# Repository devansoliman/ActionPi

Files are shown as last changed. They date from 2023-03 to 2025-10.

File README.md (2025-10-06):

# ActionPi
The open-source action camera.

## Build
1. Install `DietPi` using the [docs](https://dietpi.com/docs/install/). Add the line `dtoverlay=imx219` to `config.txt` in the `bootfs` partition.
2. Put the contents of `software` into an easily accessible directory.
3. Move `autostart.service` into `/etc/systemd/system/`. You may have to edit the path to `action.py`.
4. Run `sudo systemctl enable autostart.service`.
5. Install the following dependencies:
  - [rpi-lgpio](https://pypi.org/project/rpi-lgpio/)
  - [picamera2](https://pypi.org/project/picamera2/)
  - [luma.oled](https://luma-oled.readthedocs.io/en/latest/software.html)
  - ffmpeg
6. Open `__init__.py` in `/usr/lib/python3/dist-packages/luma/oled/device/`. Find `__init__` function under `class ssd1306(device)`. Change `height` parameter from **64** to **32**.

## Assembly Guide
🚧 In development.

### 3D Printing
I recommend using a filament with impact, UV, and fatigue resistance. Most recent prototype printed in PETG with up to 4 wall lines (0.4 mm line width).

### Parts
- Raspberry Pi Zero
- Arducam IMX219 camera (B0390)
- SSD1306 128x32 OLED
- TP4056 Li-ion charging module (USB-C input)
- 18650 Li-ion cell
- tactile button (12mm x 12mm)
- SS12D10 slide switch
- 26 AWG wire
- 2x nickel strips
- 4x m2.5 x 8mm flat head screws
- 2x m2.5 x 5mm flat head screws
- 4x m2 x 4mm flat head screws

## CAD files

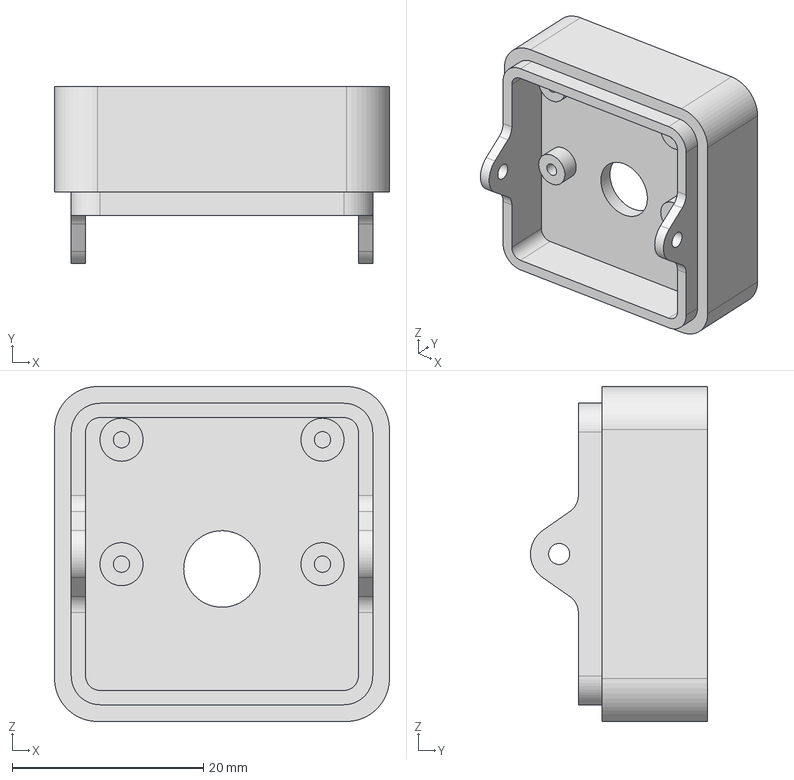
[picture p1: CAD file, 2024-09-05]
hardware/STEP/lens adapter.stp
35.0 x 18.5 x 35.0 mm

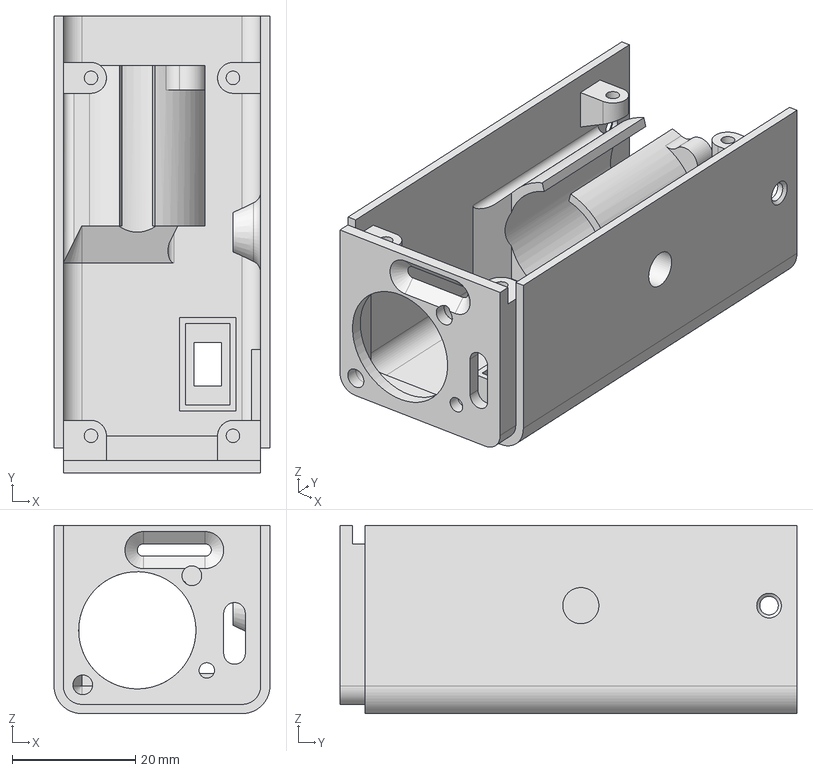
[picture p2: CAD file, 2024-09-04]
hardware/STEP/case.stp
35.0 x 74.0 x 30.5 mm

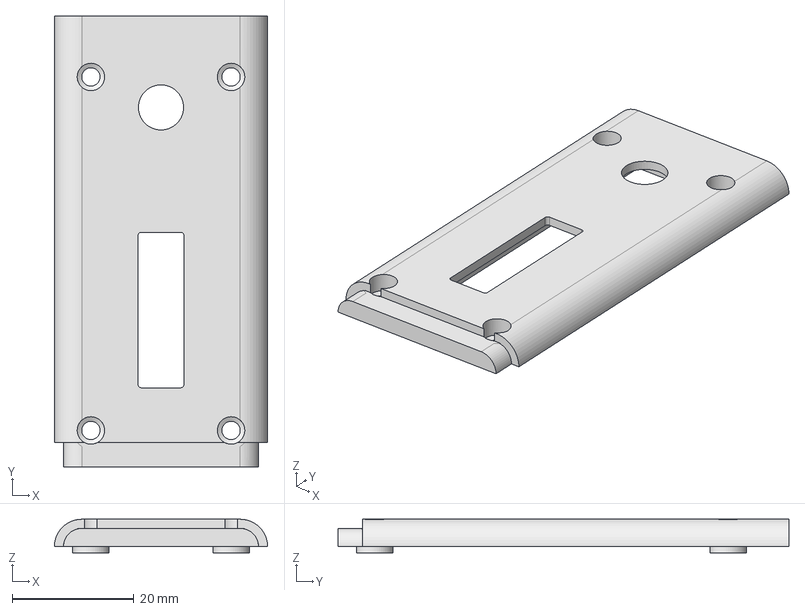
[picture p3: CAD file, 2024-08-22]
hardware/STEP/faceplate.stp
35.0 x 74.0 x 5.50 mm

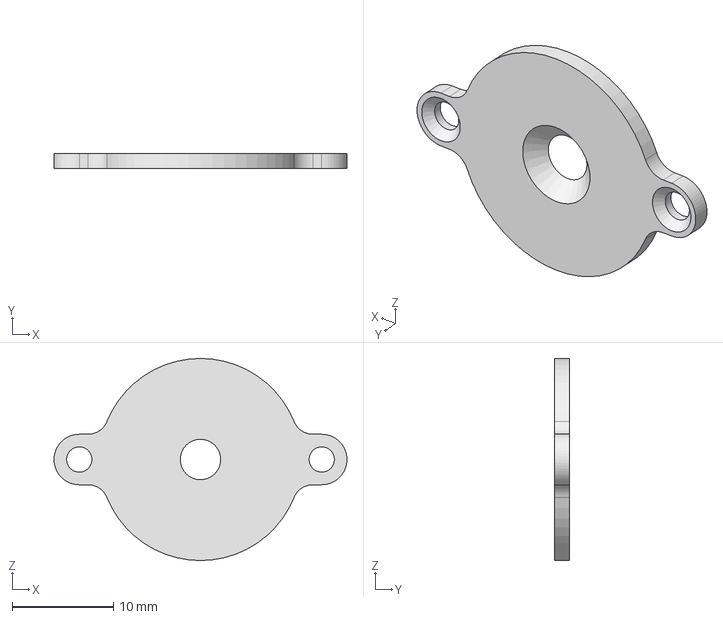
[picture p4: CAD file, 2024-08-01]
hardware/STEP/negative terminal.stp
29.0 x 1.50 x 20.0 mm

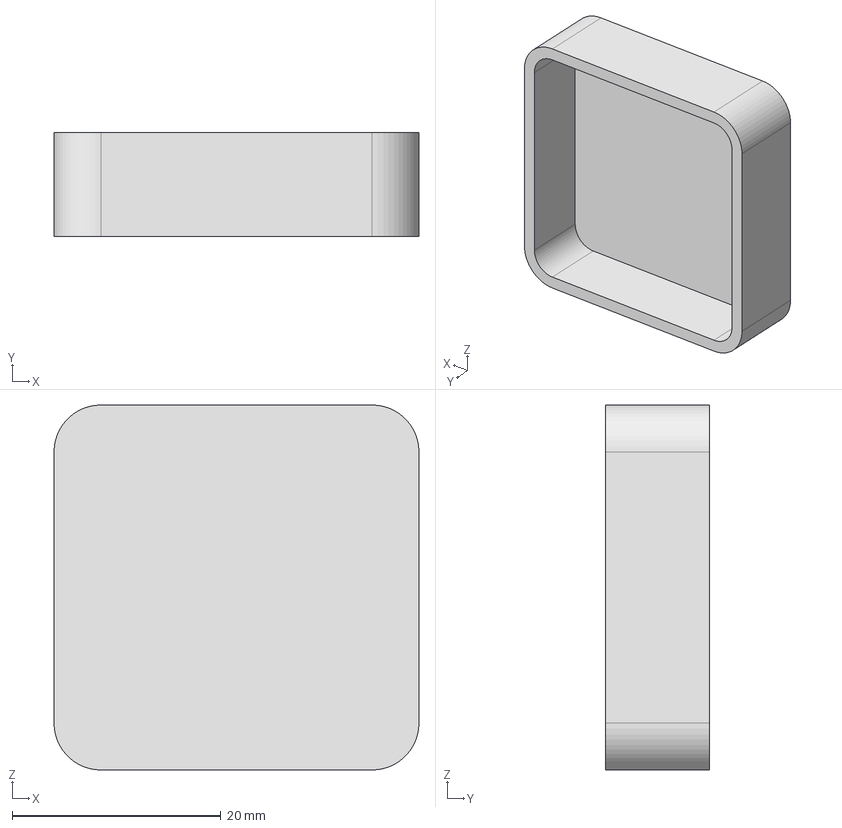
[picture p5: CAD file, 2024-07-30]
hardware/STEP/dust cap.stp
35.0 x 10.0 x 35.0 mm

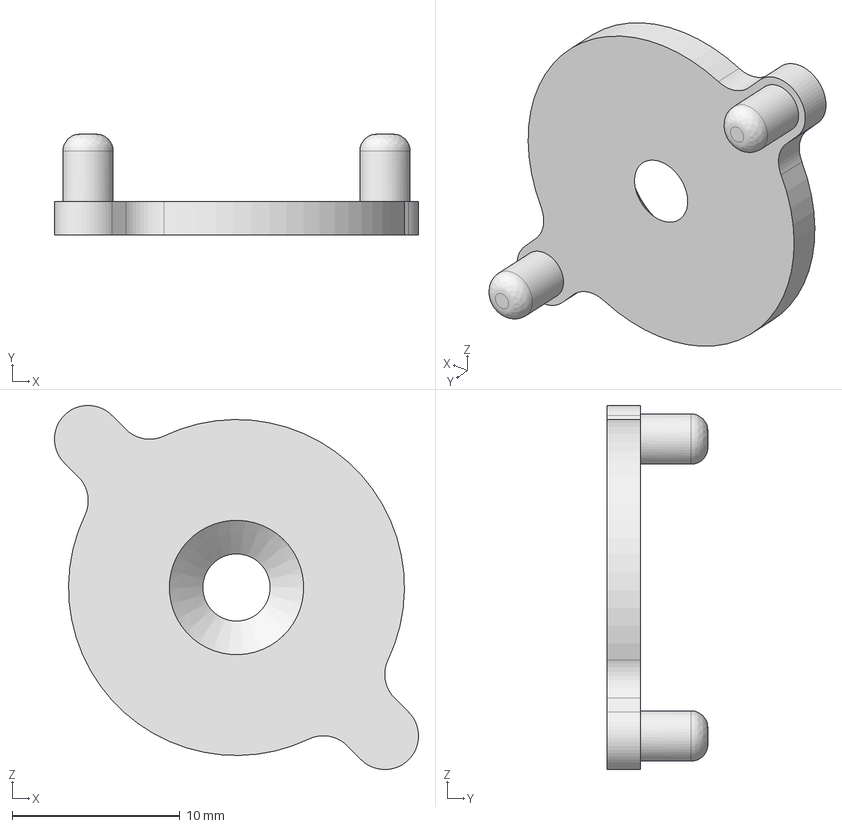
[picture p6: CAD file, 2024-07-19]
hardware/STEP/positive terminal.stp
21.7 x 6.00 x 21.7 mm

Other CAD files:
hardware/STL/case.stl
hardware/STL/dust cap.stl
hardware/STL/faceplate.stl
hardware/STL/lens adapter.stl
hardware/STL/negative terminal.stl
hardware/STL/positive terminal.stl

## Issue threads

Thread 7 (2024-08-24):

battery monitoring

devansoliman, 2024-08-24:
The Raspberry Pi Zero doesn't have an ADC, so we'll need another module to track the battery voltage.

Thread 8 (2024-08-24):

text compression

devansoliman, 2024-08-24:
`luma.oled.device.ssd1306` library uses the 128x64 version instead of 128x32

devansoliman, 2024-08-28:
Fix: change `height=64` parameter to `height=32` in `class ssd1306(device).__init__` in `/usr/lib/python3/dist-packages/luma/oled/device/__init__.py`.

Closed 2024-08-28.

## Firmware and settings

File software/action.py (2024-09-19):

import RPi.GPIO as GPIO
from picamera2 import Picamera2
from picamera2.encoders import H264Encoder
from picamera2.outputs import FfmpegOutput
from libcamera import Transform
from datetime import datetime
import threading
import os
from signal import pause

from luma.core.interface.serial import i2c
from luma.core.render import canvas
from luma.oled.device import ssd1306

from PIL import Image, ImageFont


# max CPU priority
os.nice(-20)

# video recording state
recording = False

# time counter
timer = 0

# button pin
button = 5

# configure GPIO
GPIO.setwarnings(False)
GPIO.setmode(GPIO.BCM)
GPIO.setup(button, GPIO.IN, pull_up_down=GPIO.PUD_UP)

# initialize display
serial = i2c(port=1, address=0x3C)
device = ssd1306(serial)

# splash image
splash = Image.open("splash.jpg")
device.display(splash.convert(device.mode))

# configure picamera2
picam2 = Picamera2()
video_config = picam2.create_video_configuration({"size": (1920, 1080)},
                                                 transform=Transform(hflip=1, vflip=1),
                                                 buffer_count=2)
picam2.configure(video_config)
encoder = H264Encoder()

# load custom fonts
small = ImageFont.truetype("Inter-Regular.ttf", 10)
medium = ImageFont.truetype("Inter-Bold.ttf", 16)
large = ImageFont.truetype("Inter-Bold.ttf", 30)


def arm():
    global timer
    timer = 0
    statvfs = os.statvfs("/")
    free_gb = (statvfs.f_frsize * statvfs.f_bavail) / 1000000000
    total_gb = (statvfs.f_frsize * statvfs.f_blocks) / 1000000000
    print(f"{free_gb:.2f} / {total_gb:.2f} GB FREE")

    with canvas(device) as draw:
        draw.text((0, 0), "READY", font=medium, fill="white")
        draw.text((0, 20), f"{free_gb:.2f} / {total_gb:.2f} GB", font=small, fill="white")
        # battery meter
        draw.rectangle((108, 4, 122, 14), fill="white")
        draw.rectangle((122, 6, 124, 12), fill="white")
        draw.text((110, 4), "??", font=small, fill="black")


def show_time():
    if recording:
        threading.Timer(1, show_time).start()
        global timer
        with canvas(device) as draw:
            draw.text((0, 0), f"{timer//60:02}:{timer%60:02}", font=large, fill="white")
            # battery meter
            draw.rectangle((108, 4, 122, 14), fill="white")
            draw.rectangle((122, 6, 124, 12), fill="white")
            draw.text((110, 4), "??", font=small, fill="black")
        timer += 1


def video(button):
    global recording

    if recording == False:
        timestamp = datetime.now().strftime("%Y-%m-%d-%H-%M-%S")
        output = FfmpegOutput(f"{timestamp}.mp4", audio=False)
        picam2.start_recording(encoder, output)
        recording = True
        show_time()
        print("RECORDING")
    else:
        picam2.stop_recording()
        recording = False
        print("STOPPED")
        arm()


# button event detection
GPIO.add_event_detect(button, GPIO.FALLING, video, bouncetime=250)
arm()
pause()

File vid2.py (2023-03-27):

import RPi.GPIO as GPIO
from picamera2.encoders import H264Encoder
from picamera2 import Picamera2
from datetime import datetime

button = 5

# configure GPIO
GPIO.setwarnings(False)
GPIO.setmode(GPIO.BCM)
GPIO.setup(button, GPIO.IN, pull_up_down=GPIO.PUD_UP)

# configure picamera2
picam2 = Picamera2()
video_config = picam2.create_video_configuration()
picam2.configure(video_config)
encoder = H264Encoder(bitrate=10000000)
picam2.start(show_preview=True)

while(True):
    # start recording
    GPIO.wait_for_edge(button, GPIO.FALLING)
    timestamp = datetime.now().strftime("%Y-%m-%d-%H-%M-%S")
    picam2.start_recording(encoder, f"{timestamp}.h264")

    # stop recording
    GPIO.wait_for_edge(button, GPIO.FALLING)
    picam2.stop_recording()

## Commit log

2022-12-23 Added 3D models
    Current version compatible with Raspberry Pi A+.
    [ActionPi Bottom.stl, ActionPi Button.stl, ActionPi Top.stl]
2022-12-23 Adding accessories
    Adapter allows compatibility with GoPro mounting systems.
    [ActionPi Adapter.stl, ActionPi M5 Vise.stl, M5 Thumbscrew.stl]
2022-12-26 speed boost
    Libcamera-still is launched at startup. Subsequent button presses send a signal to libcamera to take a photo.
2023-01-16 added status LED
2023-03-27 Create camera.py
    a 2-button interface for both photo and video
2023-03-27 Update camera.py
    added support for taking photos while video is recording
2023-03-27 Update camera.py
    whitespace styling
2023-03-27 Update camera.py
    added missing state change
2023-05-17 deleting unused files
    photo.py and vid.py have been combined into camera.py
2023-05-28 added version number, strengthened adapter
    [ActionPi Adapter.stl, Button.stl, Front Plate.stl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]
2023-08-27 v2 parts + reorganization
    [Button.stl, Button.stp, Front Plate.stl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]
2023-08-28 strengthen design + 1/4" mount
    [Power.stl, Power.stp, Screen.stl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]
2023-08-28 added i/o
    [Screen.stl, Screen.stp]
2023-09-06 added sensor cover
    [Camera.stl, Camera.stp]
2023-09-06 alignment fixes
    [Power.stl, Power.stp, Screen.stl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]
2023-09-06 add space for cable routing
    [Power.stl, Power.stp]
2023-09-06 add holes for GoPro mount
    [Power.stl, Power.stp]
2023-09-06 add GoPro mount
    [Mount.stl, Mount.stp]
2023-09-06 add holes for screws
    [Mount.stl, Mount.stp]
2023-09-06 add holes for magnets
    [Power.stl, Power.stp]
2023-09-08 adjust spacing
    [GoPro Adapter.stl, GoPro Adapter.stp]
2023-09-08 accessories folder + v1 compatibility
    the gopro adapter is added to a new version agnostic Accessories folder, v1 Shell gets threaded inserts for the adapter
    [GoPro Adapter.stl, GoPro Adapter.stp, Shell.stl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]
2023-09-08 remove mount hinges
    [Power.stl, Power.stp]
2023-09-08 remove folding mounts
    [Mount.stl, Mount.stp]
2023-09-08 deepen magnet wells
    [Power.stl, Power.stp]
2023-09-08 add gopro adapter compatibility
    [Power.stl, Power.stp]
2023-09-08 adjust 1/4" mount
    [Power.stl, Power.stp]
2023-09-08 add fillet
    [Camera.stl, Camera.stp]
2023-09-08 remove ribbon connector hood
    [Camera.stl, Camera.stp]
2023-09-08 shorten adapter
    [GoPro Adapter.stl, GoPro Adapter.stp]
2023-09-09 remove screen, add cover
    Cover replaces the screen window with a lower profile protective lid for the camera unit with button holes moved to the top face
    [Cover.stl, Cover.stp, Screen.stl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]
2023-09-12 add main power switch
    [Power.stl, Power.stp]
2023-09-15 status LED + main power switch
    [Cover.stl, Cover.stp, Pi.stl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]
2023-09-21 heighten
    the enclosure needs extra height to compensate for the camera's ribbon cable
    [Cover.stl, Cover.stp]
2024-07-12 add v3
    [case.stl, case.stp, dust cap.stl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]
2024-07-12 move v2 adapter to v2 folder
    [GoPro Adapter.stl, GoPro Adapter.stp]
2024-07-14 increase wall thickness
    [case.stl, case.stp, dust cap.stl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]
2024-07-14 add chamfers
    [negative terminal.stl, negative terminal.stp, positive terminal.stl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]
2024-07-14 optimizations
    - remove lip
    - thicken walls
    - adjust for Arducam
    [lens cap.stl, lens cap.stp]
2024-07-19 redesign
    - increase internal volume
    - rearrange internals
    - add power switch slot
    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
    [case.stl, case.stp, dust cap.stl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]
2024-07-20 strengthen battery socket
    [case.stl, case.stp]
2024-07-20 adjust tolerances
    [dust cap.stl, dust cap.stp]
2024-07-29 core functionality update
    - remove status led
    - remove photo button
    - add oled (ssd1306)
2024-07-30 retire v1 & v2
    [Button.stl, Button.stp, Camera.stl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]
2024-07-30 extend dust cap
    [dust cap.stl, dust cap.stp]
2024-07-30 lengthen enclosure
    [case.stl, case.stp, faceplate.stl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]
2024-07-30 minor adjustments
    - m2.5 -> m2
    - reposition sockets & lens port
    - extend lip
    [lens cap.stl, lens cap.stp]
2024-08-01 recess m2.5 sockets
    [faceplate.stl, faceplate.stp]
2024-08-01 increase negative terminal screw size
    m2 -> m2.5
    [case.stl, case.stp, negative terminal.stl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]
2024-08-04 increase screw clearance
    [faceplate.stl, faceplate.stp]
2024-08-04 3/8" - 1/4" mount
    [case.stl, case.stp]
2024-08-04 usb-c port resize
    [case.stl, case.stp]
2024-08-04 shorten 18650 well
    [case.stl, case.stp]
2024-08-05 power switch socket fix
    [case.stl, case.stp]
2024-08-05 reduce supports needed
    [case.stl, case.stp]
2024-08-21 add timer + sd space
2024-08-23 idle optimization
    leaving the camera running when not recording uses a lot of compute
2024-08-27 fix resolution + save space
    [action.py]
2024-08-28 add battery readout
    will show "??" until measurement capability is added
2024-09-05 add lens socket
    accepts lens mods designed for mobile phones
    [lens adapter.stl, lens adapter.stp, lens cap.stl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]
2025-10-06 use thinner wire
